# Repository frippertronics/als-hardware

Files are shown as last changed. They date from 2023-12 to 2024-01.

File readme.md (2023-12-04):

# Annoying Little Shit hardware

This repository contains the KiCAD design files for the
Annoying Little Shit (ALS) device, which is an AVR ATTiny13-based
device which wakes up at random intervals and beeps loudly. It is
designed to be annoying.

The buzzer is rated at 80 dB @ 4 kHz, and testing has found it to
be loud enough!

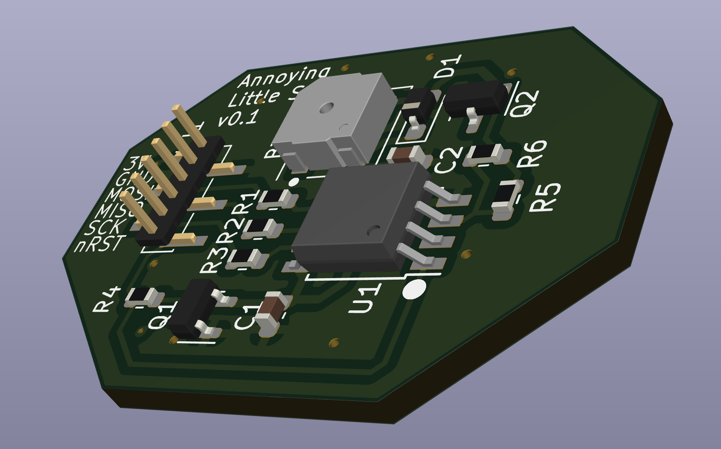
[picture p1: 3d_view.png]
3d-view


The firmware for the device can be found [here](https://github.com/frippertronics/als)!

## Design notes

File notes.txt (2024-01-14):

Specs:
- Batteridrevet (coin-cell)
- Liten
- SMD
- Piezo-buzzer -> CMT-5023S-SMT med NPN-transistor
- Vare lenge
- Programmerbar i Rust

ATTiny13V-10SU fordi den har rust board-fil
Referansedesign fra ?
Watchdog timer som våkenr opp hvert 8. sekund og øker en tellerverdi
RNG-kilde -> RNG fra ADC

Pull-up for RESET: https://onlinedocs.microchip.com/pr/GUID-F626284A-58F0-4C25-A6F3-0EA5054F3E2B-en-US-6/index.html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

Line resistance for SPI-linjer: https://onlinedocs.microchip.com/pr/GUID-F626284A-58F0-4C25-A6F3-0EA5054F3E2B-en-US-6/GUID-487B3F5E-C5E0-4DB1-9E75-CBE2E524AD06.html

Forbedringer:
- Drop pullup på nRESET -> finnes internt
- Current-limiting motstand på buzzer-output -> ubegrenset strømtrikk, ikke bra
- Pull-down på buzzer-enable, output_low er 0.7 V
- Lengre pads på buzzer-footprint -> vanskelig å lodde
- Erstatte pin-header footpring med bare 6 pads, litt enklere å lage jig
- Drop den ene motstanden på buzzer-enable, trenger bare én.
- Pull-down på ubrukte pinner

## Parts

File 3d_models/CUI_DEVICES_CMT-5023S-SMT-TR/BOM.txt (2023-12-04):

3DX_CUI_DEVICES_Supplier: CUI Devices
3DX_CUI_DEVICES_Description: 5 mm, 3 Vo-p, 80 dB, Surface Mount (SMT), Magnetic Audio Transducer Buzzer
3DX_CUI_DEVICES_Model Number: CMT-5023S-SMT-TR

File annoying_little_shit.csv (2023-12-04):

Id | Designator | Footprint | Quantity | Designation | Supplier and ref
1 | R6,R5,R1,R3,R2 | R_0603_1608Metric | 5 | 330R
2 | C2,C1 | C_0603_1608Metric | 2 | 10uF
3 | U1 | SOIC-8W_5.3x5.3mm_P1.27mm | 1 | ATtiny13V-10SU
4 | BZ1 | MagneticBuzzer_CUI_CMT-5023S-SMT | 1 | Buzzer, 3-pin
5 | J1 | PinHeader_1x06_P1.27mm_Vertical_SMD_Pin1Left | 1 | Conn_01x06_Pin
6 | R4 | R_0603_1608Metric | 1 | 10K
7 | Q1 | SOT-23 | 1 | Si2319CDS
8 | Q2 | SOT-23 | 1 | MMBT3904
9 | D1 | D_SOD-323_HandSoldering | 1 | D_Schottky
10 | BT1 | BatteryHolder_Keystone_3002_1x2032 | 1 | Battery_Cell

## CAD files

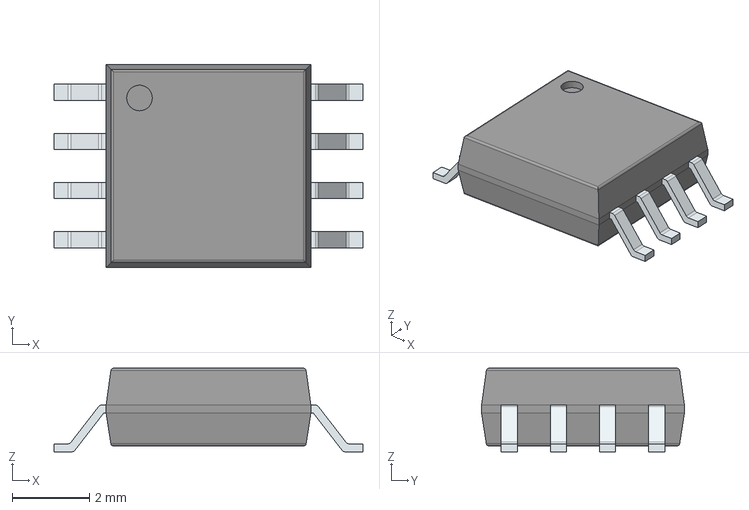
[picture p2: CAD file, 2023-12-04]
3d_models/ATTINY13V-10SU/3D/ATTINY13V-10SU.stp
7.98 x 5.24 x 2.16 mm
PinsArrayLR

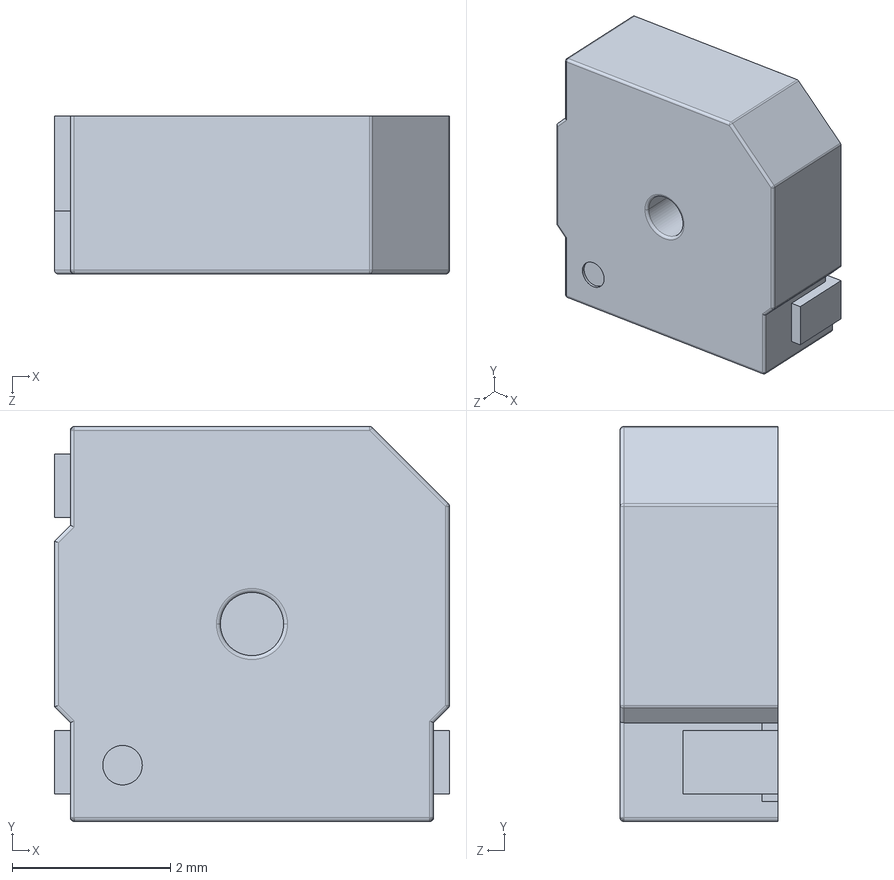
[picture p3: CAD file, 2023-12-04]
3d_models/CUI_DEVICES_CMT-5023S-SMT-TR/CUI_DEVICES_CMT-5023S-SMT-TR.step
5.00 x 5.00 x 2.00 mm

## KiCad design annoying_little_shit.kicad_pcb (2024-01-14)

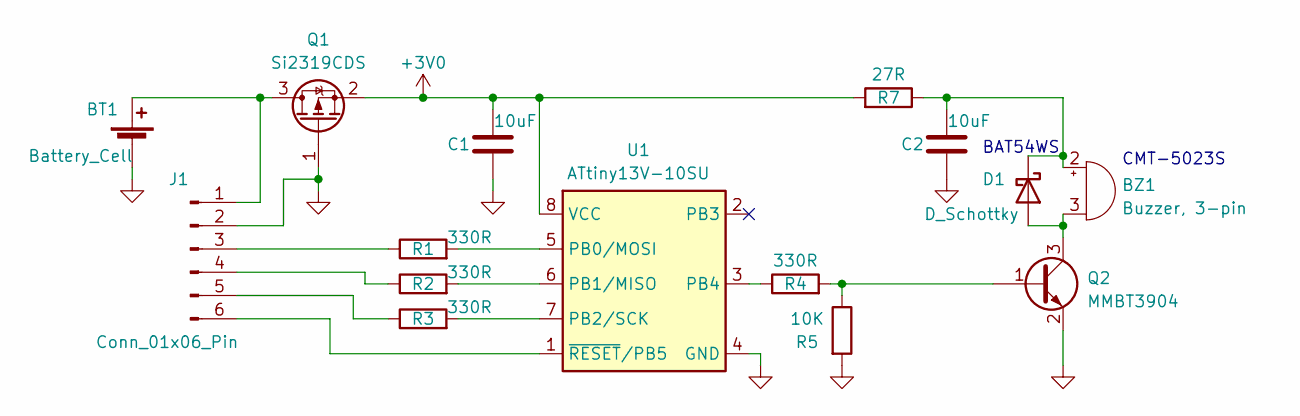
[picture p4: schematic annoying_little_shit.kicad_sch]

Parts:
BT1: Battery_Cell; BatteryHolder_Keystone_3002_1x2032
BZ1: Buzzer, 3-pin; MagneticBuzzer_CUI_CMT-5023S-SMT
C1, C2: 10uF; C_0603_1608Metric
D1: D_Schottky; D_SOD-323_HandSoldering
J1: Conn_01x06_Pin; PinHeader_1x06_P1.00mm_Vertical_SMD_Aligned
Q1: Si2319CDS; SOT-23
Q2: MMBT3904; SOT-23
R1, R2, R3, R4: 330R; R_0603_1608Metric
R5: 10K; R_0603_1608Metric
R7: 27R; R_0603_1608Metric
U1: ATtiny13V-10SU; SOIC-8W_5.3x5.3mm_P1.27mm

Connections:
+3V0: C1.1, Q1.2 (S), R7.2, U1.8 (VCC)
GND: BT1.2 (-), C1.2, C2.2, J1.2, Q1.1 (G), Q2.2 (E), R5.2, U1.4 (GND)
unnamed: BT1.1 (+), J1.1, Q1.3 (D)
unnamed: BZ1.2 (+), C2.1, D1.1 (K), R7.1
unnamed: BZ1.3 (-), D1.2 (A), Q2.3 (C)
unnamed: J1.3, R1.1
unnamed: J1.4, R2.1
unnamed: J1.5, R3.1
unnamed: J1.6, U1.1 (~RESET/PB5)
unnamed: Q2.1 (B), R4.2, R5.1
unnamed: R1.2, U1.5 (PB0/MOSI)
unnamed: R2.2, U1.6 (PB1/MISO)
unnamed: R3.2, U1.7 (PB2/SCK)
unnamed: R4.1, U1.3 (PB4)

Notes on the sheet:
CMT-5023S
BAT54WS

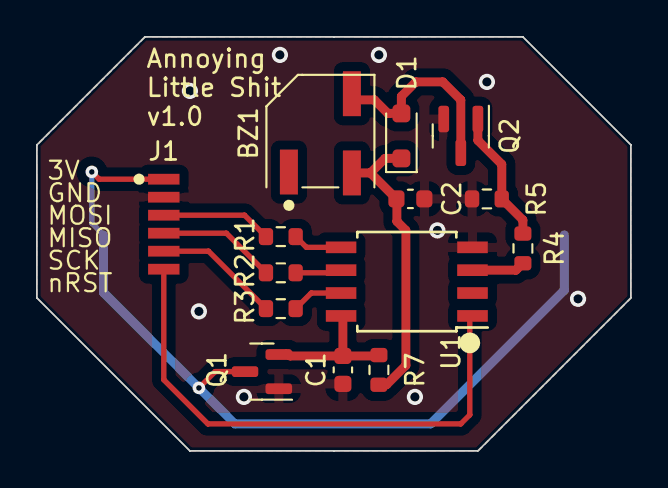
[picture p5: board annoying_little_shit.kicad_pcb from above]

Board: 2 copper layers, 33.0 x 23.0 mm, 15 parts (1 on the bottom side), 14 nets.

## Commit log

2023-12-04 Initial commit of v0.1
    [ATTINY13V-10SU.stp, CUI_DEVICES_CMT-5023S-SMT-TR.step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]
2024-01-14 Version 1.0: Current limiting resistor on buzzer, larger footprint for buzzer to make it easier to solder, remove pull-up on nRST to limit current drain (there should also be an internal one on the A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
    [annoying_little_shit.kicad_pcb, annoying_little_shit.kicad_sch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]
